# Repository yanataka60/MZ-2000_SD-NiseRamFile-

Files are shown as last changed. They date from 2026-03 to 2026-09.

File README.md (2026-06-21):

# MZ-2000_SD+偽RAMFILE複合ボード

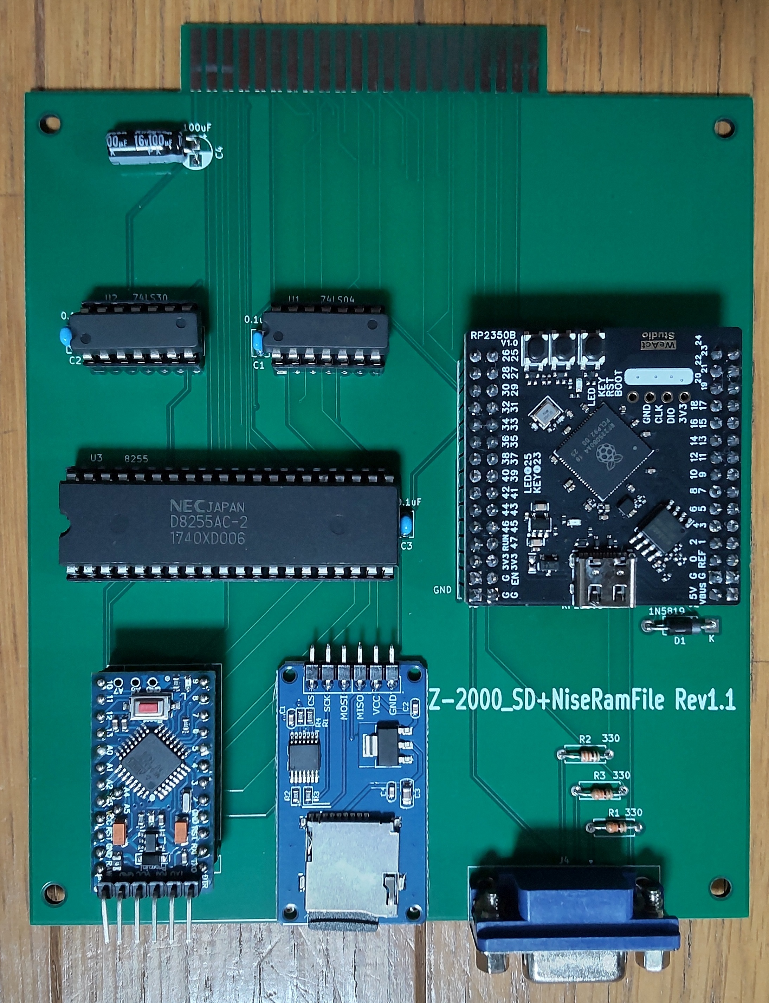
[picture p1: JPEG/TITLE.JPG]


しっぽいいんちょさんが作られた「偽RAMFILE for MZ-1500」を元にしてMZ-2000用にVRAM、GRAMのエミュレートの追加及びMZ-2000_SDと合体させたボードです。

以下の機能があります。

・MZ-2000_SDの起動及びMZ-2000_SDの機能

・EMM1からの起動(ただし、EMM1にHu-BASICの起動ディスクイメージがある場合のみ)

・MZ-2000のテキスト出力及びグラフィック出力をエミュレートしてVGA出力

・EMM1エミュレータ(320KByte)

・漢字ROMボードエミュレータ

・VGA出力される出力をI/Oポートの操作により機能強化(主にテキスト関連)

　　・キャラクタ単位でFONTの変更

　　・FONTキャラクタごとの色(前景色)及び背景色の指定

　　・すべてのキャラクタを1Dot単位で色指定可能なPCG

　　・FONTとPCGのプライオリティ設定

　　・テキストの色パレット機能

　　・グラフィックの色パレット機能

　　・テキストとグラフィックを色ごとにプライオリティ設定

MZ-2000_SD: https://github.com/yanataka60/MZ-2000_SD

#### アップロード済みのuf2ファイルでの正常動作が確認されました。当方ではSourceからの再ビルドにおいても問題は発生していません。
~~#### 2026.3.5追記 VGA出力はかなりシビアなタイミングになっています。グラフィックスを使いこなしたアクションゲームの中にはVGA出力が追いつかずに正常に表示されないものもあるようです。~~

## 回路図
　KiCadフォルダ内のMZ-2000_SD+NRF.pdfを参照してください。

[回路図](https://github.com/yanataka60/MZ-2000_SD-NiseRamFile-/blob/main/Kiacd/MZ-2000_SD%2BNRF.pdf)

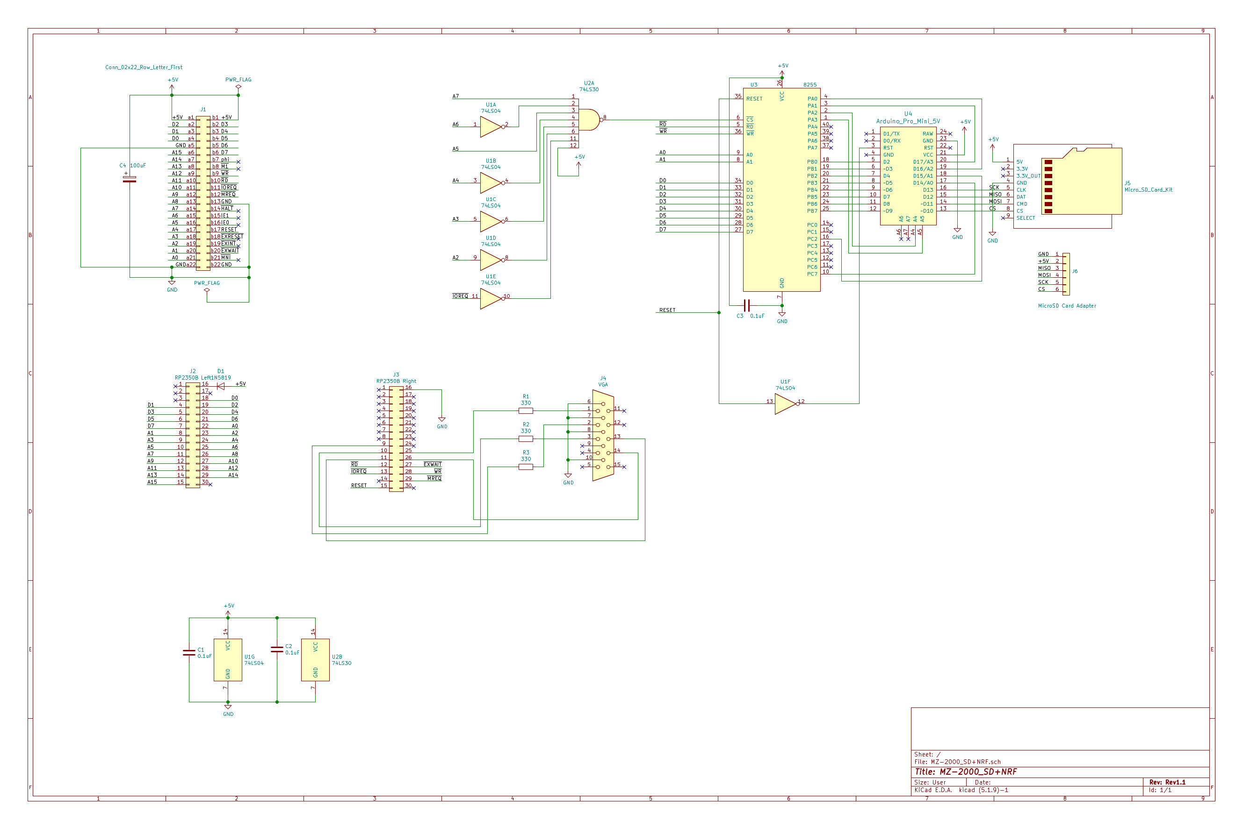
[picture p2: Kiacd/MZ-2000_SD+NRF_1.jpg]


|番号|品名|数量|備考|
| --- | --- | --- | --- |
|J2,J3|ピンソケット2x15Pin|2|RP2350Bマイコンボード用,秋月電子通商 FHU-2x42SGなど|
|J4|VGA用基板ソケット 3列15ピン|1|マルツ DJ-VGA14.5など (注1)|
||J5、J6のいずれか|||
|J5|Micro_SD_Card_Kit|1|秋月電子通商 AE-microSD-LLCNV (注2)|
|J6|MicroSD Card Adapter|1|Arduino等に使われる5V電源に対応したもの(注4)|
|U1|74LS04|1||
|U2|74LS30|1||
|U3|8255|1||
|U4|Arduino_Pro_Mini_5V|1|Atmega328版を使用 168版は不可。(注3)|
||RP2350Bボード(Raspberry Pi Pico 2)|1|Amazon WA00021 RP2350Bマイコンボードなど|
|C1-C3|積層セラミックコンデンサ 0.1uF|3||
|C4|電解コンデンサ 16v100uF|1||
|D1|ダイオード 1N5819|1||
|R1-R3|カーボン抵抗 330Ω|3||
||ピンヘッダ|2Pin分|Arduino_Pro_MiniにはA4、A5用のピンヘッダが付いていないため別途調達が必要です 秋月電子通商 PH-1x40SGなど|
||ピンソケット(任意)|26Pin分|Arduino_Pro_Miniを取り外し可能としたい場合に調達します 秋月電子通商 FHU-1x42SGなど|

　　　注1)VGA用基板ソケットには、ピン間隔の異なるものがあるようです。マルツ DJ-VGA14.5ではないものを購入する場合はこちらで寸法を確認してください。

　　　https://www.marutsu.co.jp/contents/shop/marutsu/datasheet/DJ-VGA14.5.pdf

　　　注2)秋月電子通商　AE-microSD-LLCNVのJ1ジャンパはショートしてください。

　　　注3)Arduino Pro MiniはA4、A5ピンも使っています。

　　　注4)MicroSD Card Adapterを使う場合

　　　　　J6に取り付けます。

MicroSD Card Adapterについているピンヘッダを除去してハンダ付けするのが一番確実ですが、J6の穴にMicroSD Card Adapterをぴったりと押しつけ、裏から多めにハンダを流し込むことでハンダ付けをする方法もあります。なお、この方法の時にはしっかりハンダ付けが出来たかテスターで導通を確認しておいた方が安心です。

ハンダ付けに自信のない方はJ5の秋月電子通商　AE-microSD-LLCNVをお使いください。AE-microSD-LLCNVならパワーLED、アクセスLEDが付いています。

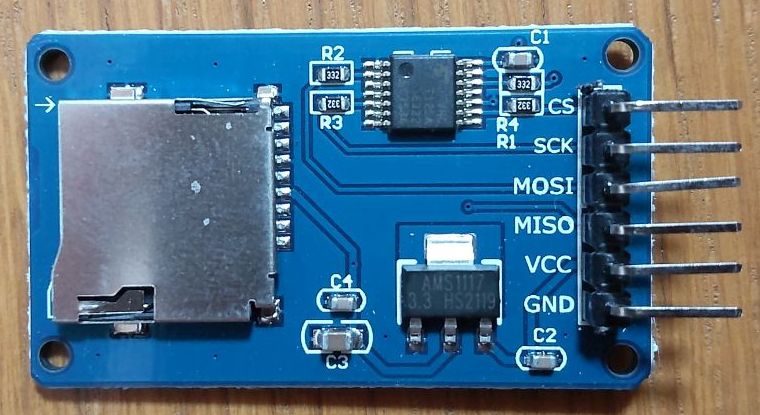
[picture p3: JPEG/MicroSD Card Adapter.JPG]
MicroSD Card Adapter1


## 偽RAMFILE for MZ-2000の書込み
　RP2350Bフォルダにあるniseramfile.uf2をRP2350Bマイコンボードに書き込みます。

　RP2350BのBOOTボタンを押しながらUSB-Cケーブルを接続するとパソコンがUSBメディアとして認識しますのでniseramfile.uf2をドロップすると自動的に書き込まれます。

　書き込みが終了するとパソコンからはUSBとして見えなくなりますのでそうなったらケーブルを抜いて終了です。

## MZ-2000_SD BOOT PROGRAMをMZ-1R12 SRAMメモリ 0番バックアップスロットへ書き込み
　MZ-2000_SDリポジトリEMMフォルダ内のBOOT_A_LOADER.binをMZ-1R12 SRAMメモリ 0番バックアップスロットへ書き込んでください。

https://github.com/yanataka60/MZ-2000_SD/blob/main/EMM/BOOT_A_LOADER.bin

　書き込みにはpicotool.exeが必要となります。以下のウェブページ右側の「Releases」からダウンロードできます。

https://github.com/raspberrypi/pico-sdk-tools

```
picotool.exe load -v -x BOOT_A_LOADER.bin  -t bin -o 0x10080000
```

　次にSDカードに「@BOOT-A MZ-2000.bin」を置きます。作成方法は、MZ-2000_SDを参照してください。

https://github.com/yanataka60/MZ-2000_SD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

　また、EMM1に起動可能な内容(HuBASIC起動イメージ)があればEMMからの起動が可能です。

　EMMの内容をチェックしていないのでEMMが起動可能な内容(HuBASIC起動イメージ)でなかった場合には暴走しますのでご注意ください。

　EMMから起動するためには、MZ-2000_SDリポジトリEMMフォルダ内の「@BOOT-EMM1.MZT」をSDカードにコピーしておく必要があります。

　EMM1からの起動方法は、「/」キーとテンキーの「1」を同時に押しながら電源ON時又はIPLリセットすることで「EMM1」のHuBASICから起動させることが出来ます。

## FONTファイルの書込み
　VGA出力を有効とするためにはMZ-2000のフォントをRP2350Bに書き込む必要があります。

　MZ-2000はソフトウェア的にフォントを取り出すすべがありません。頑張って作ってください。

　私はオーナーズマニュアルのASCIIコード表を見ながら作成しました。

　書き込みはpicotoolを使います。

```
picotool.exe load -v -x font.rom  -t bin -o 0x1001f000
```

## Arduinoプログラム
　MZ-2000_SDを参照してください。

https://github.com/yanataka60/MZ-2000_SD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

## 拡張機能の使い方
### MZ-2000_SDの起動
　MZ-2000_SDの起動方法と同じです。「/」キーを押しながら電源投入又はIPL RESETしてください。

### EMM1エミュレータ
　320KByteのEMM1として機能します。バッテリーバックアップ機能はなく、電源断で内容は消失します。

　ただし、バックアップ用のSlotが32個用意されているので電源断前にSlotに退避しておくことが可能です。

　また、Slot0の内容は電源投入又はIPL RESETした時にEMM1に自動的にコピーされるのであたかもバッテリーバックアップされていたかのような使い方が出来ます。

　EMMとSlotとのやり取りはI/Oポートから指示します。

#### SlotxxからEMM1への復帰
|アドレス|R/W|説明|
| --- | --- | --- |
|8Ch|W|指定したSlot番号(0～31)のSlotの内容をEMM1に復帰|

#### EMM1からSlotxxへの退避
|アドレス|R/W|説明|
| --- | --- | --- |
|8Dh|W|指定したSlot番号(0～31)のSlotへEMM1の内容を退避|

HuBASICからは以下のようになります。

```
OUT &H8C,0
```

```
OUT &H8D,0
```

　また、EMM1に起動可能な内容(HuBASIC起動イメージ)があればEMMからの起動が可能です。

　EMMの内容をチェックしていないのでEMMが起動可能な内容(HuBASIC起動イメージ)でなかった場合には暴走しますのでご注意ください。

　EMM1からの起動方法は、「/」キーとテンキーの「1」を同時に押しながら電源ON時又はIPLリセットすることで「EMM1」のHuBASICから起動させることが出来ます。

　EMM1へのHuBASIC起動ディスクイメージ作成は、DISK版HuBASICのUtilityからEMM1へのCOPY ALLで作ってください。

　また、Emulatorで作られたEMMイメージを登録する場合はpicotoolから以下のようにします。

```
picotool.exe load -v -x EMM_image.bin  -t bin -o 0x10280000
```

　MZ-1500_SD+NiseRamFileの様にEMMMENUも対応させたいと思います。

### 漢字・辞書ROM MZ-1R13
　漢字・辞書ROM MZ-1R13から抽出したデータを登録します。

　抽出にはGET1R13を使いました。

http://fukui.s17.xrea.com/retro/mz2080b/mzgetkrom.html

　出来上がったファイルをpicotoolで登録します。

```
picotool.exe load -v -x MZ_1R13_DIC.ROM -t bin -o 0x10040000
```

```
picotool.exe load -v -x MZ_1R13.ROM  -t bin -o 0x10020000
```

### FONT変更機能
一時的にFONTを変更することが出来ます。電源断又はIPL RESETで元に戻ります。以下VGA出力機能に関する設定は電源断又はIPL RESETですべて元に戻ります

キャラクタデータは1キャラクタ8Byteの普通のフォーマットです。

|アドレス|R/W|説明|
| --- | --- | --- |
|71h|W|データ書き込み:キャラクタコード+1|
|72h|W|キャラクタコード指定|

例)

```
OUT@$72,41:OUT@$71,$FF,OUT@$71,$FF,OUT@$71,$FF,OUT@$71,$FF,OUT@$71,$FF,OUT@$71,$FF,OUT@$71,$FF,OUT@$71,$FF
```
### FONTカラー設定
FONTのカラーを指定できます。上位4Bitがキャラクタ色(前景色)、下位4Bitが背景色になります。

|アドレス|R/W|説明|
| --- | --- | --- |
|79h|W|キャラクタ色(前景色)を上位4Bitで背景色を下位4Bitで指定する:キャラクタコード+1|
|7Ah|W|キャラクタコード指定|

例)キャラクタ「A」がGreenで表示されます。

```
OUT@$7A,41:OUT@$79,$40
```

### PCG定義
MZ-1500のPCGと同様の機能です。

1キャラクタ8Byteのキャラクタデータを3プレーン(合計24Byte)に書くことで1Dotごとに色指定が可能です。

|アドレス|R/W|説明|
| --- | --- | --- |
|61h|W|キャラクタコード指定|
|62h|W|書き込みバンク指定(Blue:1,Red:2,Green:3)|
|63h|W|データ書き込み:キャラクタコード+1|

### PCGの表示切替、FONTテキストとの優先順位変更
MZ-1500のPCGと同様の機能です。

Bit0でPCG表示の切り替え、Bit1でテキストとPCGの優先順位が変更できます。

|67h|W|Bit1 優先順位 0:テキスト文字色＞PCG＞テキスト背景色<br>　　　　　　1:PCG＞テキスト<br>Bit0 PCG表示  0:PCGを表示しない<br>　　　　　　1:PCGを表示する|

### テキストパレット設定
テキストの色について上位4Bitで表す色コードを下位4Bitで表す色に変えることが出来ます。

|アドレス|R/W|説明|
| --- | --- | --- |
|68h|W|上位4Bitで表す色コードを下位4Bitで表す色で表示する<br>　起動時設定<br>　　0x00<br>　　0x11<br>　　0x22<br>　　0x33<br>　　0x44<br>　　0x55<br>　　0x66<br>　　0x77|

例)起動時WhiteのテキストをGreenに変える

```
OUT@$68,$74
```

### グラフィックパレット設定
テキストの色とは別にグラフィックの色について上位4Bitで表す色コードを下位4Bitで表す色に変えることが出来ます。

|アドレス|R/W|説明|
| --- | --- | --- |
|69h|W|上位4Bitで表す色コードを下位4Bitで表す色で表示する<br>　起動時設定<br>　　0x00<br>　　0x11<br>　　0x22<br>　　0x33<br>　　0x44<br>　　0x55<br>　　0x66<br>　　0x77|

例)色指定7のグラフィックをGreenに変える

```
OUT@$69,$74
```

### グラフィックとテキストの優先順位変更
MZ-2000ではI/Oポート$F5によりテキストとグラフィックの優先順位を変更可能ですが、こちらを使うことで色ごとに優先順位を変更することが出来ます。

|アドレス|R/W|説明|
| --- | --- | --- |
|6Ah|W|上位4Bitで表す色コードを0Bitが1の時、グラフィック優先、0の時テキスト優先|

## MZ-80B、MZ-2500の80Bモードでの使用について
　MZ-2000_SD機能、EMM1エミュレータ、漢字ROMボードエミュレータはMZ-80B、MZ-2500の80Bモードでも問題なく動作しますが、VGA出力機能はVRAM、GRAMのアクセス方法がMZ-2000と異なるためまともな表示となりません。

## SAMPLE
### DEEP SCAN カラー化
　キャラクタに色を付けるサンプルプログラムを作ってみました。

　えむこまさんが公開されているMZ-80K/C版からの移植DEEP SCAN用に作ってみました。

https://github.com/mkomakonkon/MZ-2000/tree/master/IO/198005_DEEP_SCAN

　フォントファイルを入れ替える必要があるためEmuz-2200用とされていましたがMZ-2000_SD+偽RAMFILE複合ボードなら遊ぶことが出来ます。

　えむこまさんのサイトからダウンロードしたDEEP SCAN.zipを解凍するとFONT.ROMというファイルが含まれていますのでSampleフォルダのDEEP SCANフォルダにある「SET COLOR DEEP SCAN.mzt」の後ろにバイナリエディタなどでくっつけて一つのMZTファイルとします。

　また、DEEP SCANの実行ファイルであるDEEP SCAN.wavはDumpList Editorなどを使ってMZTファイル化してください。(実行アドレスを2000hに指定してMZTファイル化すると便利です)

　後はDEEP SCAN.MZTを実行する前にSET COLOR DEEP SCAN.mztを実行するだけです。

### グリーンモニター化
　カラーパレット機能を設定してキャラクタ、グラフィックともグリーン一色表示に変える「GREEN-MONITOR.mzt」をSampleフォルダのGREEN MONITORフォルダに置きました。

　MZ-2000_SD起動直後に実行すれば以降はグリーンモニターとなります。

　GVRAMを切り替えて表示するパラパラアニメ等にお使いください。

## おまけ
　グラフィックボードを装着していないMZ-2000でもVGA出力からカラーグラフィックが正常に利用できるバージョンを作ってみました。

　uf2ファイル

https://github.com/yanataka60/MZ-2000_SD-NiseRamFile-/blob/main/OMAKE/RP2350B/niseramfile_No_GVRAM.uf2

　ソースファイル

https://github.com/yanataka60/MZ-2000_SD-NiseRamFile-/tree/main/OMAKE/Source(No_GVRAM)

### 使用上の注意
　グラフィックボートが装着されていないこと。

　プレーン1のみのグラフィックボートが装着されている場合も取り外してください。

　MZ-2200もグラフィックボートを取り外せば使えます。

　MZ-80B、MZ-2500(80B、2000、2500モードとも)では正常に動作しません。通常のバージョンを使ってください。

## 開発環境、使用ライブラリなど
　開発環境は、Visual Studio Codeです。

　VGAライブラリは以下を使用しています。

- [VGA ライブラリ(一部改変)](https://github.com/vha3/Hunter-Adams-RP2040-Demos/tree/master/VGA_Graphics)

## 謝辞
　素晴らしい拡張モジュールを開発し、自由に改変・公開を快く承諾してくださったしっぽいいんちょさん、ありがとうございました。

## 追記
2026.3.5 kuran_kuran様よりkuran_kuran様作成ゲームでVGA出力が追いついていない事例の報告がありました。

2026.3.5 アップロード済みのuf2ファイルにおいては正常にVGA出力されることが確認されました。なお、niseramfile.cが$6Aポートの制御が抜けているファイルでしたので更新しました。

2026.3.6 使用ライブラリの記載を追加。

2026.3.6 Sampleプログラムを追加しました。

2026.3.7 開発環境を追記。

2026.3.16 おまけとしてNo_GVRAMバージョンを追加。

2026.3.27 Sampleフォルダに「GREEN-MONITOR.mzt」を追加。

2026.6.21 MZ-2000_SD+偽RAMFILE複合ボードに電源が供給されている状態でUSB-Cケーブルを接続してはいけない問題に対してすーぱーたーぼさんからご指摘いただいた対策を施しました。Rev1.0基板でも通常の使用でMZ-2000_SD+偽RAMFILE複合ボードに電源が供給されている状態でUSB-Cケーブルを接続することはありませんので通常使用においてRev1.0基板でも問題ありません。

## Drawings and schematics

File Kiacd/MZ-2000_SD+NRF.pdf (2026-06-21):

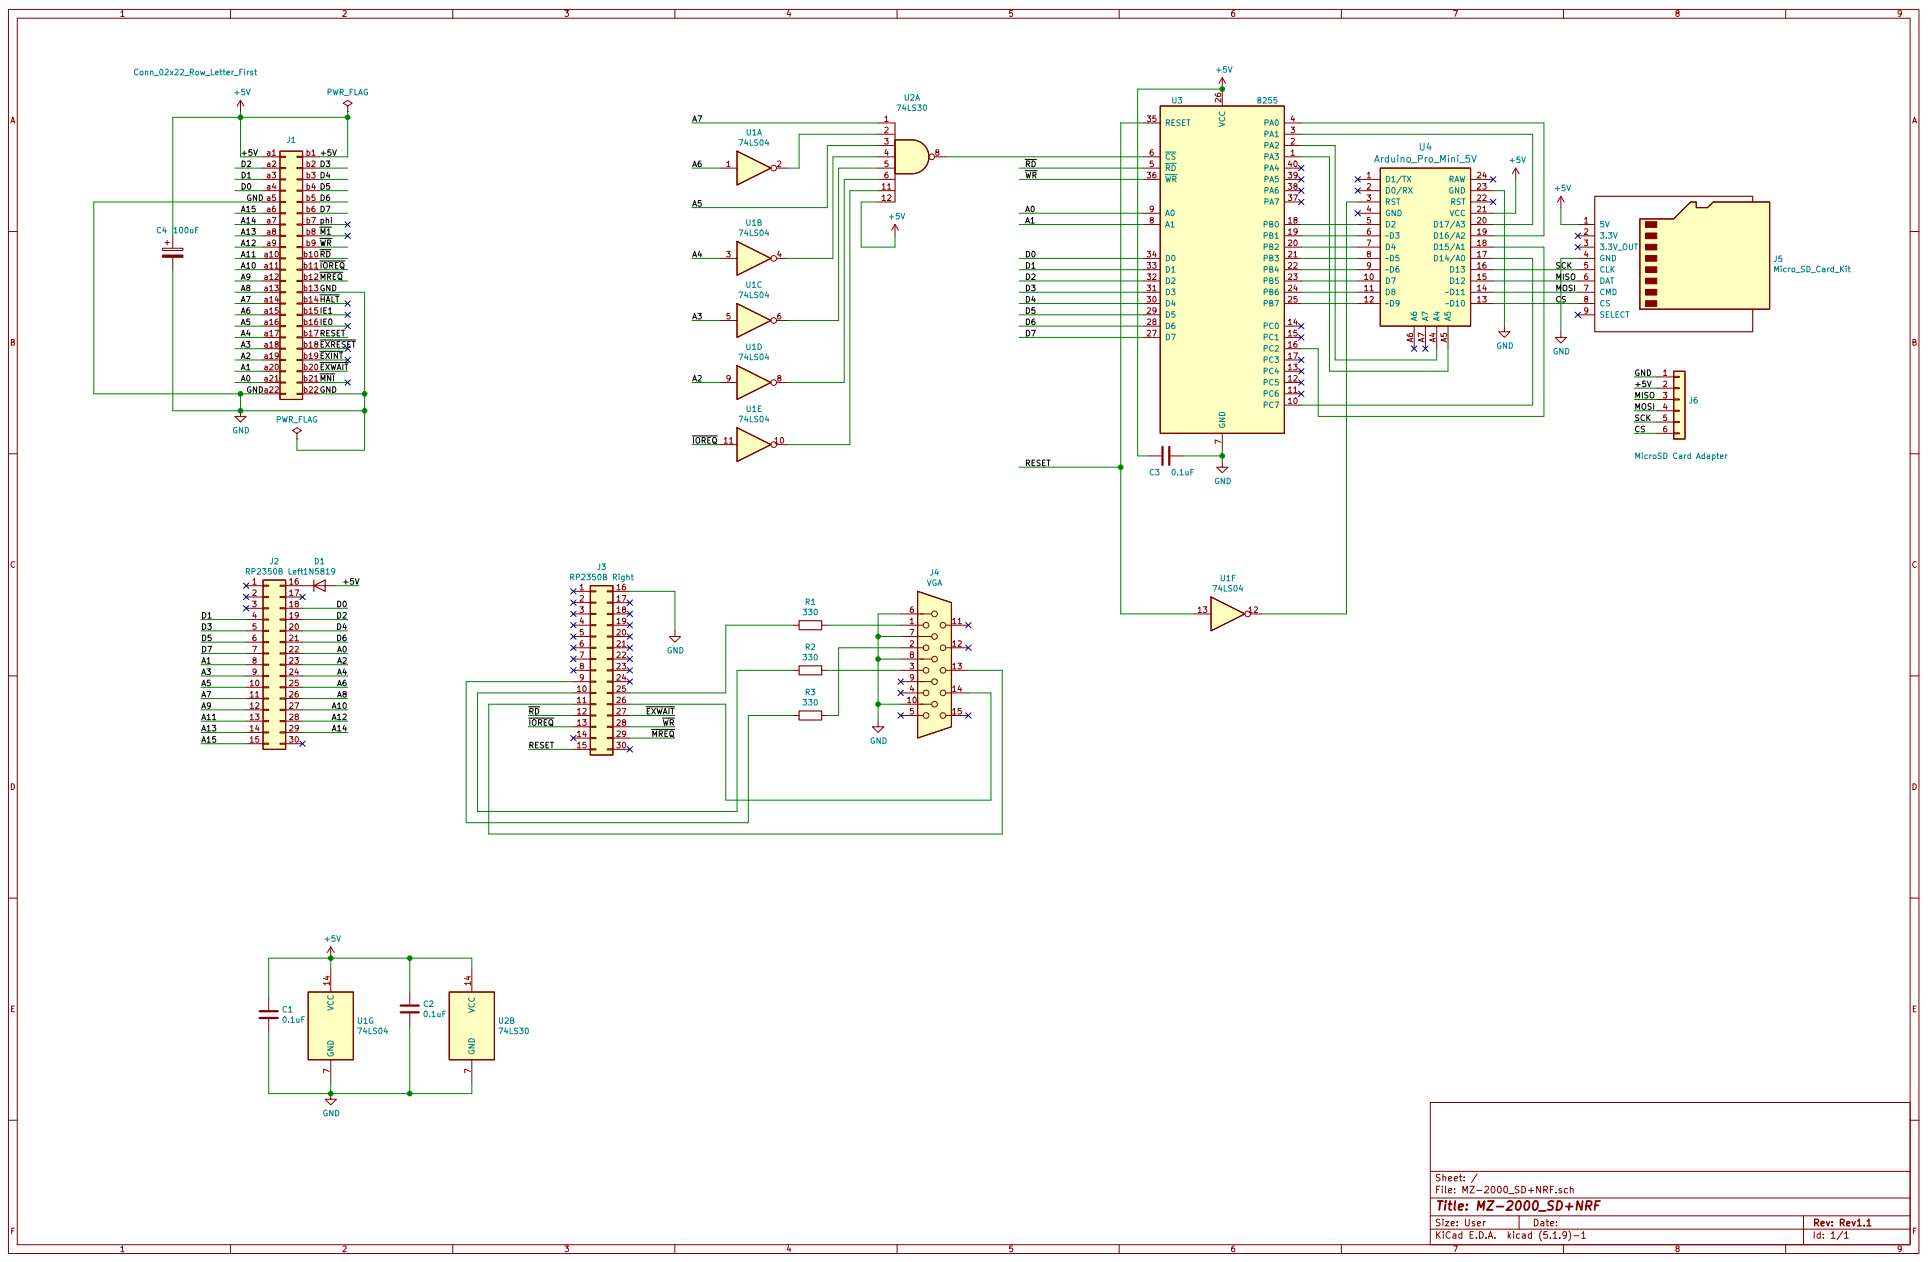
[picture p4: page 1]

7 A1 8 A0 9 U3 8255 D1/TX 1 D7 10 D8 11 D9 12 D10 13 D11 14 D12 15 D13 16 D14/A0 17 D15/A1 18 D16/A2 19 D0/RX 2 D17/A3 20 VCC 21 RST 22 GND 23 RAW 24 RST 3 GND 4 D2 5 D3 6 D4 7 D5 8 D6 9 A4 A4 A5 A5 A6 A6 A7 A7 U4 Arduino_Pro_Mini_5V

File: MZ-2000_SD+NRF.sch Sheet: /
Id: 1/1 Title: MZ-2000_SD+NRF

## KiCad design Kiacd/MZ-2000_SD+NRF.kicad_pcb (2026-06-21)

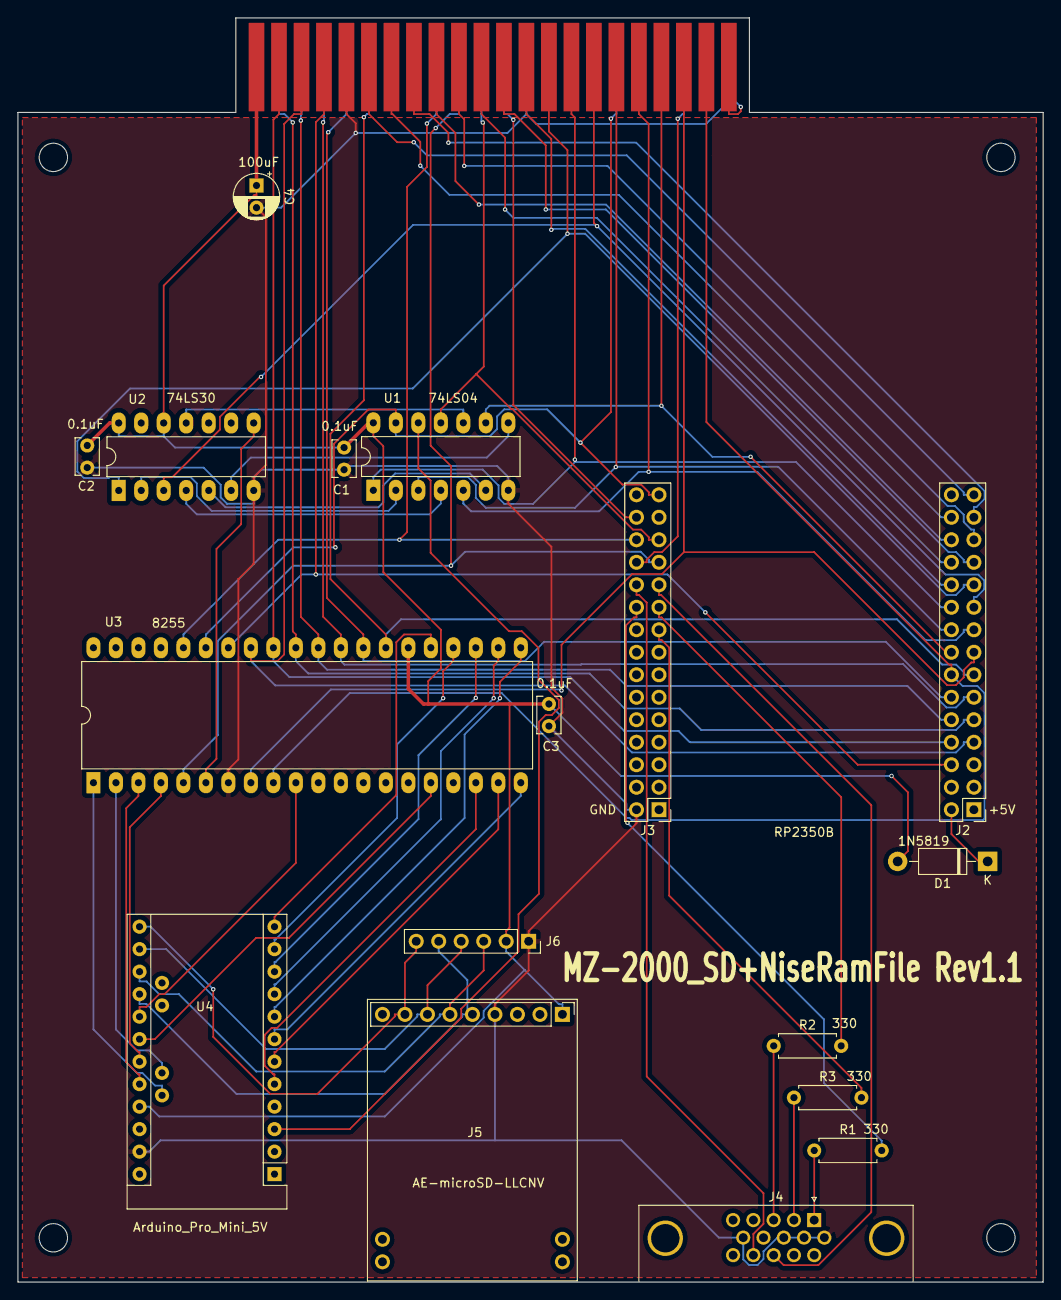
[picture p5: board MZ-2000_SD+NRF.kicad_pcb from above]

Board: 2 copper layers, 115.8 x 142.7 mm, 22 parts (0 on the bottom side), 66 nets.

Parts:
C1, C2, C3: 0.1uF; C_Rect_L4.0mm_W2.5mm_P2.50mm
C4: 100uF; CP_Radial_D5.0mm_P2.50mm
D1: BAT54; D_DO-41_SOD81_P10.16mm_Horizontal
J1: Conn_02x22_Row_Letter_First; BUS_MZ2000
J2: RP2350B Left; PinHeader_2x15_P2.54mm_Vertical
J3: RP2350B Right; PinHeader_2x15_P2.54mm_Vertical
J4: VGA; DSUB-15-HD_Female_Horizontal_P2.29x1.98mm_EdgePinOffset3.03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
J5: Micro_SD_Card_Kit; AE-microSD-LLCNV
J6: MicroSD Card Adapter; PinSocket_1x06_P2.54mm_Vertical
MH1, MH2, MH3, MH4: MountingHole_3.2mm_M3
R1, R2, R3: 330; R_Axial_DIN0207_L6.3mm_D2.5mm_P7.62mm_Horizontal
U1: 74LS04; DIP-14_W7.62mm_LongPads
U2: 74LS30; DIP-14_W7.62mm_LongPads
U3: 8255; DIP-40_W15.24mm_LongPads
U4: Arduino_Pro_Mini_5V; Arduino_Pro_Mini

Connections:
+5V: C1.1, C2.1, C3.1, C4.1, D1.2, J1.a1, J1.b1, J5.1, J6.2, U1.14, U2.12, U2.14, U3.26, U4.21
/A0: J1.a21, J2.22, U3.9
/A1: J1.a20, J2.8, U3.8
/A2: J1.a19, J2.23, U1.9
/A3: J1.a18, J2.9, U1.5
/A4: J1.a17, J2.24, U1.3
/A5: J1.a16, J2.10, U2.3
/A6: J1.a15, J2.25, U1.1
/A7: J1.a14, J2.11, U2.1
/A8: J1.a13, J2.26
/A9: J1.a12, J2.12
/A10: J1.a11, J2.27
/A11: J1.a10, J2.13
/A12: J1.a9, J2.28
/A13: J1.a8, J2.14
/A14: J1.a7, J2.29
/A15: J1.a6, J2.15
/CS: J5.8, J6.6, U4.13
/D0: J1.a4, J2.18, U3.34
/D1: J1.a3, J2.4, U3.33
/D2: J1.a2, J2.19, U3.32
/D3: J1.b2, J2.5, U3.31
/D4: J1.b3, J2.20, U3.30
/D5: J1.b4, J2.6, U3.29
/D6: J1.b5, J2.21, U3.28
/D7: J1.b6, J2.7, U3.27
/MISO: J5.6, J6.3, U4.15
/MOSI: J5.7, J6.4, U4.14
/RESET: J1.b17, J3.15, U1.13, U3.35
/SCK: J5.5, J6.5, U4.16
/~EXWAIT: J1.b20, J3.27
/~IOREQ: J1.b11, J3.13, U1.11
/~MREQ: J1.b12, J3.29
/~RD: J1.b10, J3.12, U3.5
/~WR: J1.b9, J3.28, U3.36
GND: C1.2, C2.2, C3.2, C4.2, J1.a5, J1.a22, J1.b13, J1.b22, J3.16, J4.6, J4.7, J4.8, J4.10, J5.4, J6.1, U1.7, U2.7, U3.7, U4.23
unnamed: D1.1, J2.16
unnamed: J3.9, R3.2
unnamed: J3.10, R2.2
unnamed: J3.11, J4.13
unnamed: J3.25, R1.2
unnamed: J3.26, J4.14
unnamed: J4.1, R1.1
unnamed: J4.2, R3.1
unnamed: J4.3, R2.1
unnamed: U1.2, U2.2
unnamed: U1.4, U2.4
unnamed: U1.6, U2.5
unnamed: U1.8, U2.6
unnamed: U1.10, U2.11
unnamed: U1.12, U4.3
unnamed: U2.8, U3.6
unnamed: U3.1, U4.A5
unnamed: U3.2, U4.A4
unnamed: U3.3, U4.20
unnamed: U3.4, U4.19
unnamed: U3.10, U4.17
unnamed: U3.16, U4.18
unnamed: U3.18, U4.5
unnamed: U3.19, U4.6
unnamed: U3.20, U4.7
unnamed: U3.21, U4.8
unnamed: U3.22, U4.9
unnamed: U3.23, U4.10
unnamed: U3.24, U4.11
unnamed: U3.25, U4.12

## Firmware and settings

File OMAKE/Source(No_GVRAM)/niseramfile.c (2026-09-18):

//  MZ-2000 Multi-function RAMFILE card 'Niseramfile'
//
//  MZ-1R12: Boot device for MZ-2000
//  MZ-1R13: Kanji ROM
//  PIO-3034: EMM

//  MZ-2000 extention slot
//  GP0-7:  D0-7
//  GP8-23: A0-15
//  GP25: RESET -> Interrupt
//  GP28: MERQ
//  GP29: IORQ
//  GP30: WR
//  GP31: RD
//  GP32: EXWAIT

#define FLASH_INTERVAL 300      // 5sec

#include <stdio.h>
#include <stdlib.h>
#include <string.h>

#include "pico/stdlib.h"
#include "pico/multicore.h"
#include "pico/sync.h"
#include "hardware/pio.h"
#include "hardware/clocks.h"
#include "hardware/timer.h"
#include "hardware/uart.h"
#include "hardware/flash.h"
#include "hardware/sync.h"
#include "hardware/vreg.h"

#include "vga16_graphics.h"

#include "misc.h"
//#include "hardware/xip_cache.h"

#define RESET_PIN 25
#define MONITOR_PIN 40

// RAM configuration
// MZ-1R12: 32KiB
// EMM:    320KiB

uint8_t __attribute__  ((aligned(sizeof(unsigned char *)*4096))) mz1r12[0x10000];
uint8_t __attribute__  ((aligned(sizeof(unsigned char *)*4096))) mz1r18[0x10000];
uint8_t __attribute__  ((aligned(sizeof(unsigned char *)*4096))) emm[0x50000];

// PCG emulation (33KiB)
//// VRAM  4KiB
//// CGRAM 4Kib
//// PCG   24KiB
//// COLOR 256Byte
// GRAPHIC (48KiB)

uint8_t vram[0x2000];
uint8_t cgram[0x1000];
uint8_t pcg[0x2000 * 3];
uint8_t tcolor[0x100];

// 16KB x3 plane
uint8_t gvramb[0x4000];
uint8_t gvramr[0x4000];
uint8_t gvramg[0x4000];

volatile uint8_t vram_enabled;
volatile uint8_t pcg_enabled;
volatile uint8_t text40_mode=0;
volatile uint8_t graphic_write_enable=0;
volatile uint8_t graphic_write_plane=0;
volatile uint8_t graphic_enable=0;
volatile uint8_t graphic_plane_enable = 0x07;
bool green_monitor = 1;
// bit0 = B plane
// bit1 = R plane
// bit2 = G plane

uint8_t screen_bg_color = 0; // 0〜7 (MZパレットindex)

// GRAPHIC color priority
uint8_t graphic_prio[8] = {
    0, // color0 transparent
    0, // behind TEXT
    0, // over TEXT
    0,
    0,
    0,
    0,
    0
};
/*

0 = TEXT優先（TEXTがあれば描かない）

1 = GRAPHIC優先（必ず描く）

*/

#define MAXROMPAGE 64       // =  32KiB * 64 pages =  2MiB
#define MAXEMMPAGE 32       // = 320KiB * 32 pages = 10MiB

volatile uint8_t rompage=0;  // Page No of MZ-1R12 (64KiB/page)
volatile uint8_t emmpage=0;  // Page No of EMM (320KiB/page)

volatile uint32_t kanjiptr=0;
volatile uint32_t dictptr=0;
volatile uint32_t select_kanji=0;
volatile uint32_t kanjictl=0;
volatile uint32_t mz1r18ptr=0;
volatile uint32_t mz1r12ptr=0;
volatile uint32_t emmptr=0;
volatile uint16_t tclptr=0;
volatile uint32_t flash_command=0;
volatile uint32_t font_ptr=0;
volatile uint32_t tcolor_ptr=0;
volatile uint32_t pcg_ptr=0;

// ROM configuration
// WeACT RP2350B with 16MiB Flash
// FONT ROM         4KiB   @ 0x1001f000
// Kanji ROM        128KiB @ 0x10020000
// Jisho ROM        256KiB @ 0x10040000
// Data for 1R12    32KiB  * 64 = 2MiB  @ 0x10080000
// Data for EMM     320KiB * 32 = 10MiB @ 0x10280000

#define ROMBASE 0x10080000u

uint8_t *fontrom=(uint8_t *)(ROMBASE-0x61000);
uint8_t *kanjirom=(uint8_t *)(ROMBASE-0x60000);
uint8_t *jishorom=(uint8_t *)(ROMBASE-0x40000);
uint8_t *romslots=(uint8_t *)(ROMBASE);
uint8_t *emmslots=(uint8_t *)(ROMBASE+(0x8000*MAXROMPAGE));

// VGA Output
uint8_t scandata[640];
//uint8_t scandata[320];
extern unsigned char vga_data_array[];
volatile uint32_t video_hsync,video_vsync,scanline,vsync_scanline;
volatile uint8_t pcg_control;
volatile uint8_t pcg700_control,pcg700_data;
volatile uint8_t pcg_bank;
uint8_t pallet[8];
uint8_t gpallet[8];

uint8_t colors[16]; // DUMMY

//uint8_t __attribute__  ((aligned(sizeof(unsigned char *)*4096))) flash_buffer[4096];

void __not_in_flash_func(mzscan)(uint8_t scan);
void __not_in_flash_func(mzscan80)(uint8_t scan);
void __not_in_flash_func(mzscan40)(uint8_t scan);

// *REAL* H-Sync for emulation
void __not_in_flash_func(hsync_handler)(void) {

    uint32_t vramindex;
    uint32_t tmsscan;
    uint8_t bgcolor;

    pio_interrupt_clear(pio0, 0);

    if((scanline!=0)&&(gpio_get(VSYNC)==0)) { // VSYNC
        scanline=0;
        video_vsync=1;
    } else {
        scanline++;
    }

    if((scanline%2)==0) {
        video_hsync=1;

        // VDP Draw on HSYNC

        // VGA Active starts scanline 35
        //          Active scanline 78(0) to 477(199)

        if((scanline>=73)&&(scanline<=472)) {
//        if((scanline>=81)&&(scanline<=480)) {

            tmsscan=(scanline-73)/2;
//            tmsscan=(scanline-81)/2;
            vramindex=(tmsscan%4)*640;
//            vramindex=(tmsscan%4)*320;

            mzscan(tmsscan);

            for(int j=0;j<640;j++) {
//            for(int j=0;j<320;j++) {
                vga_data_array[vramindex+j]=scandata[j];
            }           
        }

    }

    return;

}

//
//  reset

void __not_in_flash_func(z80reset)(uint gpio,uint32_t event) {

//    gpio_acknowledge_irq(RESET_PIN,GPIO_IRQ_EDGE_FALL);
    gpio_acknowledge_irq(RESET_PIN,GPIO_IRQ_EDGE_RISE);

    if(gpio_get(RESET_PIN)==0) return;

    kanjiptr=0;
    dictptr=0;
    kanjictl=0;
	select_kanji=0;
    mz1r18ptr=0;
    mz1r12ptr=0;
    emmptr=0;
    tclptr=0;
    pcg_control=0;

    vram_enabled=0;
    pcg_enabled=0xff;
	pcg_bank=0;

	text40_mode=0;
	graphic_write_enable=0;
	graphic_write_plane=0;
	graphic_enable=0;
	graphic_plane_enable = 0x07;
	screen_bg_color = 0;

// GPIO40 初期化（グリーンモニタ判定）
	gpio_init(MONITOR_PIN);
	gpio_set_dir(MONITOR_PIN, false);  // INPUT
	gpio_pull_down(MONITOR_PIN);       // 必要に応じて（環境次第）
	sleep_us(10);                      // 安定待ち

	green_monitor = gpio_get(MONITOR_PIN);
	
	if (green_monitor) {
    // グリーンモニタ用（全色を緑系へ）
	    pallet[0] = 0;
	    gpallet[0] = 0;
	    for(int i=1;i<8;i++) {
	        pallet[i] = 4;   // 緑固定
	        gpallet[i] = 4;
	    }
	} else {
    // 通常カラー
	    for(int i=0;i<8;i++) {
	        pallet[i]=i;
	        gpallet[i]=i;
	    }
	}
	
	memcpy(cgram,fontrom,0x1000);

	for(uint16_t offset=0;offset<0x100;offset++){
		tcolor[offset]=0x70;
	}

	for(int i=0;i<8;i++) {
		graphic_prio[i]=0;
	}

    for(uint16_t i=0;i<0x2000;i++) {
        vram[i]=0;
    }

    for(uint16_t i=0;i<0x4000;i++) {
        gvramb[i]=0;
        gvramr[i]=0;
        gvramg[i]=0;
    }

	return;
}

// ======================================================
// VGA Scan Dispatch
// ======================================================

void __not_in_flash_func(mzscan)(uint8_t scan)
{
    if(text40_mode)
        mzscan80(scan);
    else
        mzscan40(scan);
}


static uint8_t textbgflag[640];

void __not_in_flash_func(mzscan80)(uint8_t scan)
{

	uint8_t scany  = scan>>3;
	uint8_t scanyy = scan&7;

	uint8_t *dst=scandata;
	uint8_t *bgf=textbgflag;

	uint8_t *v=vram+(scany*80);

	uint8_t pcg1=pcg_control&1;
	uint8_t pcg2=pcg_control&2;


//---------------- TEXT + PCG ----------------

	for(int scanx=0;scanx<80;scanx++){

		uint8_t ch=*v++;

		uint8_t color=tcolor[ch]&0x77;

		uint8_t fg=(color>>4)&7;
		uint8_t bg=color&7;

		uint8_t font=cgram[(ch<<3)+scanyy];

		uint32_t *bf=&bitexpand[(uint32_t)font<<2];

		uint32_t f1=bf[1]*fg;
		uint32_t f2=bf[0]*fg;

		uint32_t b1=bf[3]*bg;
		uint32_t b2=bf[2]*bg;

		uint32_t p1=0;
		uint32_t p2=0;

// PCG

		if(pcg1){
			uint32_t base=(ch<<3)+scanyy;

			uint32_t *bb=&bitexpand[(uint32_t)pcg[base]<<2];
			uint32_t *br=&bitexpand[(uint32_t)pcg[base+0x2000]<<2];
			uint32_t *bgp=&bitexpand[(uint32_t)pcg[base+0x4000]<<2];

			p1=bb[1]+br[1]*2+bgp[1]*4;
			p2=bb[0]+br[0]*2+bgp[0]*4;
		}
		uint8_t *tf1=(uint8_t*)&f1;
		uint8_t *tf2=(uint8_t*)&f2;

		uint8_t *tb1=(uint8_t*)&b1;
		uint8_t *tb2=(uint8_t*)&b2;

		uint8_t *tp1=(uint8_t*)&p1;
		uint8_t *tp2=(uint8_t*)&p2;

// 前半

		for(int i=0;i<4;i++){

			uint8_t px=tb1[i];
			uint8_t bgonly=1;

			if(pcg2){

				if(tp1[i]){ px=tp1[i]; bgonly=0; }
					else if(tf1[i]){ px=tf1[i]; bgonly=0; }

			}else{

				if(tf1[i]){ px=tf1[i]; bgonly=0; }
					else if(tp1[i]){ px=tp1[i]; bgonly=0; }

			}

			*dst++=pallet[px];
			*bgf++=bgonly;
		}
// 後半

		for(int i=0;i<4;i++){

			uint8_t px=tb2[i];
			uint8_t bgonly=1;

			if(pcg2){

				if(tp2[i]){ px=tp2[i]; bgonly=0; }
					else if(tf2[i]){ px=tf2[i]; bgonly=0; }

			}else{

				if(tf2[i]){ px=tf2[i]; bgonly=0; }
					else if(tp2[i]){ px=tp2[i]; bgonly=0; }

			}

			*dst++=pallet[px];
			*bgf++=bgonly;

		}

	}


//------------- GRAPHIC -------------

	if(graphic_enable && scan<200){

		uint32_t offs=scan*80;

		uint8_t pen=graphic_plane_enable;

		uint8_t *dstg=scandata;
		uint8_t *bg=textbgflag;

		for(int bx=0;bx<80;bx++){

			uint8_t vb=(pen&1)?gvramb[offs+bx]:0;
			uint8_t vr=(pen&2)?gvramr[offs+bx]:0;
			uint8_t vg=(pen&4)?gvramg[offs+bx]:0;

			uint32_t b=
			bitexpand[vb*4]
				+bitexpand[vr*4]*2
				+bitexpand[vg*4]*4;

			uint32_t f=
			bitexpand[vb*4+1]
				+bitexpand[vr*4+1]*2
				+bitexpand[vg*4+1]*4;

			uint8_t *p1=(uint8_t*)&b;
			uint8_t *p2=(uint8_t*)&f;

			#define DRAW(px)\
				{\
					uint8_t v=(px);\
					if(v){\
						uint8_t col=gpallet[v];\
						if(graphic_prio[v] || *bg)\
							*dstg=col;\
						}\
						dstg++;\
						bg++;\
				}

				DRAW(p1[3]);
				DRAW(p1[2]);
				DRAW(p1[1]);
				DRAW(p1[0]);

				DRAW(p2[3]);
				DRAW(p2[2]);
				DRAW(p2[1]);
				DRAW(p2[0]);
			#undef DRAW
		}
	}
}

void __not_in_flash_func(mzscan40)(uint8_t scan)
{

	uint8_t scany=scan>>3;
	uint8_t scanyy=scan&7;

	uint32_t offset=scany*40;

	uint8_t *dst=scandata;
	uint8_t *bgf=textbgflag;

	uint8_t pcg1=pcg_control&1;
	uint8_t pcg2=pcg_control&2;


// TEXT

	for(int x=0;x<40;x++){

		uint8_t ch=vram[offset++];

		uint8_t color=tcolor[ch]&0x77;

		uint8_t fg=(color>>4)&7;
		uint8_t bg=color&7;

		uint8_t font=cgram[(ch<<3)+scanyy];

		uint32_t *bf=&bitexpand[(uint32_t)font<<2];

		uint32_t f1=bf[0]*fg;
		uint32_t f2=bf[1]*fg;

		uint32_t b1=bf[2]*bg;
		uint32_t b2=bf[3]*bg;

		uint32_t p1=0,p2=0;

		if(pcg1){

			uint32_t base=(ch<<3)+scanyy;

			uint32_t *bb=&bitexpand[(uint32_t)pcg[base]<<2];
			uint32_t *br=&bitexpand[(uint32_t)pcg[base+0x2000]<<2];
			uint32_t *bgp=&bitexpand[(uint32_t)pcg[base+0x4000]<<2];

			p1=bb[0]+br[0]*2+bgp[0]*4;
			p2=bb[1]+br[1]*2+bgp[1]*4;
		}

		uint8_t *tf1=(uint8_t*)&f1;
		uint8_t *tf2=(uint8_t*)&f2;

		uint8_t *tb1=(uint8_t*)&b1;
		uint8_t *tb2=(uint8_t*)&b2;

		uint8_t *tp1=(uint8_t*)&p1;
		uint8_t *tp2=(uint8_t*)&p2;

		uint8_t buf[8];
		uint8_t bgfbuf[8];

		for(int i=0;i<4;i++){

			uint8_t px=tb1[i];
			uint8_t bgonly=1;

			if(pcg2){

				if(tp1[i]){px=tp1[i];bgonly=0;}
					else if(tf1[i]){px=tf1[i];bgonly=0;}

			}else{

				if(tf1[i]){px=tf1[i];bgonly=0;}
					else if(tp1[i]){px=tp1[i];bgonly=0;}

			}

			buf[i+4]=px;
			bgfbuf[i+4]=bgonly;
		}

		for(int i=0;i<4;i++){

			uint8_t px=tb2[i];
			uint8_t bgonly=1;

			if(pcg2){

				if(tp2[i]){px=tp2[i];bgonly=0;}
					else if(tf2[i]){px=tf2[i];bgonly=0;}

		}else{

			if(tf2[i]){px=tf2[i];bgonly=0;}
				else if(tp2[i]){px=tp2[i];bgonly=0;}

		}

		buf[i]=px;
		bgfbuf[i]=bgonly;
	}


// double x

		for(int i=0;i<8;i++){

			uint8_t col=pallet[buf[i]];

			*dst++=col;
			*dst++=col;

			*bgf++=bgfbuf[i];
			*bgf++=bgfbuf[i];

		}

	}
// GRAPHIC

	if(graphic_enable && scan<200){

		uint32_t offs=scan*80;

		uint8_t pen=graphic_plane_enable;

		uint8_t *dstg=scandata;
		uint8_t *bg=textbgflag;

		for(int bx=0;bx<80;bx++){

			uint8_t vb=(pen&1)?gvramb[offs+bx]:0;
			uint8_t vr=(pen&2)?gvramr[offs+bx]:0;
			uint8_t vg=(pen&4)?gvramg[offs+bx]:0;

			uint32_t b=
				bitexpand[vb*4]
				+bitexpand[vr*4]*2
				+bitexpand[vg*4]*4;

			uint32_t f=
				bitexpand[vb*4+1]
				+bitexpand[vr*4+1]*2
				+bitexpand[vg*4+1]*4;

			uint8_t *p1=(uint8_t*)&b;
			uint8_t *p2=(uint8_t*)&f;

			#define DRAW(px)\
			{\
				if(px){\
					uint8_t col=gpallet[px];\
					if(graphic_prio[px] || *bg)\
						*dstg=col;\
				}\
				dstg++;\
				bg++;\
			}

			DRAW(p1[3]);
			DRAW(p1[2]);
			DRAW(p1[1]);
			DRAW(p1[0]);

			DRAW(p2[3]);
			DRAW(p2[2]);
			DRAW(p2[1]);
			DRAW(p2[0]);

			#undef DRAW

		}
	}
}


static inline void io_write(uint16_t address, uint8_t data)
{

    uint8_t b;

    switch(address&0xff) {

        // MZ-1R13

        case 0xb8:  // Kanji PTR Lo
	    	kanjiptr=(kanjiptr & 0xff00) | (data << 0);
            return;

        case 0xb9:  // Kanji PTR Hi
			kanjiptr=(kanjiptr & 0x00ff) | (data << 8);
            return;

		case 0xba:
			select_kanji = ((data & 1) != 0);
            return;

    	case 0xbb:  // Kanji PTR ++
			kanjiptr++;
            return;

        // MZ-1R12

        case 0xf8:  // MZ-1R12 ptr High 
            mz1r12ptr=(data<<8)+(mz1r12ptr&0xff);
            mz1r12ptr&=0x7fff;
            return;

        case 0xf9:  // MZ-1R12 ptr Low
            mz1r12ptr=data+(mz1r12ptr&0xff00);
            return;

        //  MZ-1R12 control 

        case 0x8a:
            rompage=data&0x3f;
            flash_command=0x10000000+(data&0x3f);
            return;

        case 0x8b:
            rompage=data&0x3f;
            flash_command=0x20000000+(data&0x3f);
            return;

        case 0x8c:
            emmpage=data&0x1f;
            flash_command=0x30000000+(data&0x1f);        
            // FLASHからEMMのmemcpy完了を待つ
            while(flash_command != 0) {
                tight_loop_contents();
            }
            return;

        case 0x8d:
            emmpage=data&0x1f;
            flash_command=0x40000000+(data&0x1f);        
            return;

        // EMM
        case 0xa4:
            emmptr=(emmptr&0x7ff00)+(data);
            return;

        case 0xa5:
            emmptr=(emmptr&0x700ff)+(data<<8);
            return;           

        case 0xa6:
//            emmptr=(emmptr&0xffff)+(data<<16);
            emmptr=(emmptr&0xffff)+((data&7)<<16);
            return; 

        case 0xa7:
            if(emmptr>0x4ffff) {
                emmptr-=0x50000;
            }
            emm[emmptr++]=data;
            return;

//		PCG SET

    	// PCG ADDRESS RESET
    	case 0x60:
            pcg_ptr=0;
            return;
    	// PCG ADDRESS SET
        case 0x61:
    		pcg_ptr=data*8;
			return;
//        case 0xe5:  // BANK TO PCG
        case 0x62:  // BANK TO PCG
            pcg_bank=data&3;
            return;
    	// PCG WRITE & PCG ADDRESS++
        case 0x63:
            if((pcg_bank&3)!=0) {
    	 		pcg[pcg_ptr+((pcg_bank&3)-1)*0x2000]=data;
            }
    		pcg_ptr++;
            return;

    	// VGA Out

//        case 0xF0:
        case 0x67:
            pcg_control=data;
            return;

//        PALLET CONTROL
//        case 0xF1:
        case 0x68:
			if (green_monitor==0) {
            	pallet[(data&0x70)>>4]=data&7;
			};
            return;

//        GRAPHIC PALLET CONTROL
//        case 0xF1:
        case 0x69:
			if (green_monitor==0) {
	            gpallet[(data&0x70)>>4]=data&7;
			};
			return;

//        GRAPHIC color priority
        case 0x6A:
			graphic_prio[(data&0x70)>>4]=data&1;
            return;

    	// BANK control

//		FONT CHANGE

    	// FONT ADDRESS RESET
    	case 0x70:
            font_ptr=0;
            return;
    	// FONT WRITE & FONT ADDRESS++
        case 0x71:
            cgram[font_ptr]=data;
    		font_ptr++;
            return;
    	// FONT ADDRESS SET
        case 0x72:
    		font_ptr=data*8;
			return;

    	// FONT ADDRESS RESET
    	case 0x78:
            tcolor_ptr=0;
            return;
    	// FONT COLOR SET & FONT ADDRESS++
        case 0x79:
            tcolor[tcolor_ptr]=data;
    		tcolor_ptr++;
            return;
    	// FONT COLOR SET ADDRESS
        case 0x7a:
    		tcolor_ptr=data;
			return;

//        case 0xe3:  // BANK TO VRAM
    	case 0xe8:
    		vram_enabled = ((data & 0xC0) == 0xC0);
    		if ((data & 0xC0) == 0x80){
    			graphic_write_enable =1;
    		} else {
    			graphic_write_enable =0;
    		}
    	
    		text40_mode =  ((data & 0x20) == 0x20);
    		return;

        case 0xF7:  // BANK TO GRAM
			graphic_write_plane = (data & 0x03);
    		return;

        case 0xF6:  // BANK TO GRAM
		    graphic_enable = !!(data & 0x07);
    		graphic_plane_enable = (data & 0x07);
    		return;

        case 0xF5:  // GRAPHIC color priority
			if (green_monitor==0) {
	            pallet[0x07]=data&7;
			};

            if(data & 0x08){
				for(int i=0;i<8;i++) {
				graphic_prio[i]=1;
				}
            } else {
				for(int i=0;i<8;i++) {
				graphic_prio[i]=0;
				}
            }
    		return;

		case 0xF4:
    		for(uint16_t i=0;i<0x100;i++){
    			tcolor[i]=(tcolor[i]&0xF0)+(data & 0x07);
    		}
			return;

    }
 
    return;

}

static inline void memory_write(uint16_t address, uint8_t data)
{
	/* vram_enabled == 1 かつ address < 0xE000 */
    if (vram_enabled && address < 0xE000 && address >= 0xD000){
        vram[address & 0x0FFF] = data;
    	return;
    }

    /* address >= 0xC000 の場合のみGRAM書き込み */
    if (graphic_write_enable && address >= 0xC000){
        switch (graphic_write_plane){
        	case 0x01:
            	gvramb[address & 0x3FFF] = data;
            	break;
        	case 0x02:
            	gvramr[address & 0x3FFF] = data;
            	break;
        	case 0x03:
            	gvramg[address & 0x3FFF] = data;
            	break;
	        default:
    	    	break;
        }
    	return;
    }
    return;
}

void init_emulator(void) {

    // Erase Gamepad info

    kanjiptr=0;
    mz1r12ptr=0;
    mz1r18ptr=0;
    emmptr=0;
    tclptr=0;
    pcg_control=0;
    vram_enabled=0;
    pcg_enabled=0xff;
	pcg_bank=0;

	text40_mode=0;
	graphic_write_enable=0;
	graphic_write_plane=0;
	graphic_enable=0;
	graphic_plane_enable = 0x07;
	screen_bg_color = 0;

// GPIO40 初期化（グリーンモニタ判定）
	gpio_init(MONITOR_PIN);
	gpio_set_dir(MONITOR_PIN, false);  // INPUT
	gpio_pull_down(MONITOR_PIN);       // 必要に応じて（環境次第）
	sleep_us(10);                      // 安定待ち

	green_monitor = gpio_get(MONITOR_PIN);
	
	if (green_monitor) {
    // グリーンモニタ用（全色を緑系へ）
	    pallet[0] = 0;
	    gpallet[0] = 0;
	    for(int i=1;i<8;i++) {
	        pallet[i] = 4;   // 緑固定
	        gpallet[i] = 4;
	    }
	} else {
    // 通常カラー
	    for(int i=0;i<8;i++) {
	        pallet[i]=i;
	        gpallet[i]=i;
	    }
	}

    for(int i=0;i<8;i++) {
        graphic_prio[i]=0;
    }

    for(uint16_t i=0;i<0x2000;i++) {
        vram[i]=0;
    }

    for(uint16_t i=0;i<0x4000;i++) {
        gvramb[i]=0;
        gvramr[i]=0;
        gvramg[i]=0;
    }

// コピー前に割り込みを止める
	uint32_t ints = save_and_disable_interrupts();

	memcpy(cgram,fontrom,0x1000);

    // Load DUMMY data to MZ-1R12

    memcpy(mz1r12,romslots,0x8000);
//    memset(mz1r12,0xaa,0x8000);

    // Load EMM data to EMM

	memcpy(emm,emmslots,0x50000);

	restore_interrupts(ints);

	for(uint16_t offset=0;offset<0x100;offset++){
		tcolor[offset]=0x70;
	}

}

// Main thread (Core1)

void __not_in_flash_func(main_core1)(void) {

    volatile uint32_t bus;

    uint32_t control,address,data,response;
	uint32_t offset2;
	uint8_t value;
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
int main() {

    uint32_t menuprint=0;
    uint32_t filelist=0;
    uint32_t subcpu_wait;
    uint32_t rampacno;
    uint32_t pacpage;

    static uint32_t hsync_wait,vsync_wait;

    vreg_set_voltage(VREG_VOLTAGE_1_20);  // for overclock to 200MHz
    set_sys_clock_khz(300000 ,true);

	gpio_put(RESET_PIN, 0);

	init_emulator();
    initVGA();
    multicore_launch_core1(main_core1);

	gpio_put(RESET_PIN, 1);
	
    irq_set_exclusive_handler (PIO0_IRQ_0, hsync_handler);
    irq_set_enabled(PIO0_IRQ_0, true);
    pio_set_irq0_source_enabled (pio0, pis_interrupt0 , true);

    // Set RESET# interrupt

//    gpio_set_irq_enabled_with_callback(RESET_PIN,GPIO_IRQ_EDGE_FALL,true,z80reset);
    gpio_set_irq_enabled_with_callback(RESET_PIN,GPIO_IRQ_EDGE_RISE,true,z80reset);

    while(1) {

        if(flash_command!=0) {

            switch(flash_command&0xf0000000) {

                case 0x10000000:  // SRAM load
                    memcpy(mz1r12,romslots+(flash_command&0x3f)*0x8000u,0x8000);
                    break;

                case 0x20000000:  // SRAM Save

                    for(uint32_t i=0;i<0x8000;i+=4096) {
                    uint32_t ints = save_and_disable_interrupts();
//                    multicore_lockout_start_blocking();     // pause another core
                    flash_range_erase(i+0x80000u+(flash_command&0x3f)*0x8000u, 4096);  
//                    multicore_lockout_end_blocking();
                    restore_interrupts(ints);
                    }

                    for(uint32_t i=0;i<0x8000;i+=4096) {
                    uint32_t ints = save_and_disable_interrupts();
//                    multicore_lockout_start_blocking();     // pause another core
                    flash_range_program(i+0x80000u+(flash_command&0x3f)*0x8000u, (const uint8_t *)(mz1r12+i), 4096);
//                    multicore_lockout_end_blocking();
                    restore_interrupts(ints);
                    }

                    break;

                case 0x30000000:  // EMM load
                    memcpy(emm,emmslots+(flash_command&0x1f)*0x50000u,0x50000);
                    break;                    

                case 0x40000000:  // EMM Save

                    for(uint32_t i=0;i<0x50000;i+=4096) {
                    uint32_t ints = save_and_disable_interrupts();
//                    multicore_lockout_start_blocking();     // pause another core
                    flash_range_erase(i+0x280000u+(flash_command&0x1f)*0x50000u, 4096);
//                    multicore_lockout_end_blocking();
                    restore_interrupts(ints);
                    }

                    for(uint32_t i=0;i<0x50000;i+=4096) {
                    uint32_t ints = save_and_disable_interrupts();
//                    multicore_lockout_start_blocking();     // pause another core
                    flash_range_program(i+0x280000u+(flash_command&0x1f)*0x50000u, (const uint8_t *)(emm+i), 4096);
//                    multicore_lockout_end_blocking();
                    restore_interrupts(ints);
                    }

                    break;  

            }
            flash_command=0;

        }
    }
}
